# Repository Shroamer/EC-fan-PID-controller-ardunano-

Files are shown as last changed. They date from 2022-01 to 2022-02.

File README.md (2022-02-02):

# EC-fan-PID-controller-ardunano-
**PID controller**
Govern EC fan (0...10v PWM control line) as a PID temperature controller. 
Based on arduino nano v3 (atmega328) dev.board
Termperature sensor is ds18b20 on 1-wire
UI oled screen 128x32 ssd1306 on i2c
UI input encoder with switch on interrupts

## r2.2.5
**beta (in test)**
 + fixed hysteresis function (don't let fan to turn on for some time after it turned off)
 + added destagnation function (turn fan to minPower for some time if no fan activity was found past some time)
 + power icon now can morph to HYST and DEST icons if in these modes.
 + fixed issue with rapid plot overflow while screen is turned off. Now plot array is fulfilled more evenly.
 + fixed value overflow in cycling thru variables

### The device is used to govern EC fan thru 0...10v control line using temperature reading from ds18b20 digital sensor.
- It utilize **ssd1306 128x32 oled display** to show various data and plot graphs.
- Use **encoder with button** to roll thru displays and enter settings. _(with acceleration)_
- ds18b20 **1-wire digital temperature sensor** connected via 3 wire with GND and +5v, _supposedly to make reading routine faster. but i did not find any mentions of id it is faster than on parasitic power_
- Arduino is **powered by** GND and +10v from fan's control line. (my sample use **<35ma** with most pixels white) _I was about to use arduino pro mini, but voltage regulator is too weak to drive arduino and screen, so i turned to nano as it has more powerful +5v voltage regulator_
- PWM signal is raised to 10v and **inverted** with two transistors. _Inversion is used to prevent fan from stopping in case of device failure. Discussible._

### Various variables and data can be set and read:
- Goal temperature.
- PID variables: **kP**, **kI**, **kD** and overall **multiplier** (0.01...100).
- There is a **P+I+D math display** on multiplier screen for you to have deeper understanding of how your config works.
- **MinPower** (some fans can't run at less than 5 or 10%)
- **MaxPower** (sometimes you don't want fan to go full speed)
- You can set **hysteresys delay** in seconds. Think of it as a _cool-down time you need to wait after turning fan off before turning it on again_. It prevents fan from going fast on-off at a margin values.
- There is a **destagnant ventilation** function that can run fan for a while if no fan activity was found recently. _This prevents air from stagnation even there's no need to cool._
- **Temperature offset** can be entered -9.0...9.0^ (0.1^ increment) if your sensor lies linearly.
- **Display timeout** 0...600sec so oled display will last longer.
- You can **turn image 180^** and encoder reading will be inverted.
- Manual and automatic **store setting** to EEPROM on case of power loss.
- You can avoid EEPROM degradation restricting to store current screen. _It is convenient while configuring, but isn't needed after._
- You can play with PId parameters with AUSTOISAVE OFF, and then **restore settings from EEPROM**, or save new settings if new config is better.
- **Temperature graph plot** show last 128 readings for diagnostics.
- **PIDoutput graph plot** show last 128 output values, so you can diagnose and configure PID.
- **Plot sampling rate** can be adjusted averaging up to 250 reading in a single data line in plot, so you can log longer periods. _(sample rate is approx. 3rps)_
- **Automatic vertical range** for graph plots. _Set-mode will change it to full range._
- You can **manually set output rate**. This mode is stored into EEPROM to **return after power loss**. 
- Device maintains manual mode with last stored value **if temp.sensor is lost**.
- Device maintains manual mode **if screen has failed**.

EC-FAN-pid controller r2 2_bb
EC-FAN-pid controller r2 2_schem

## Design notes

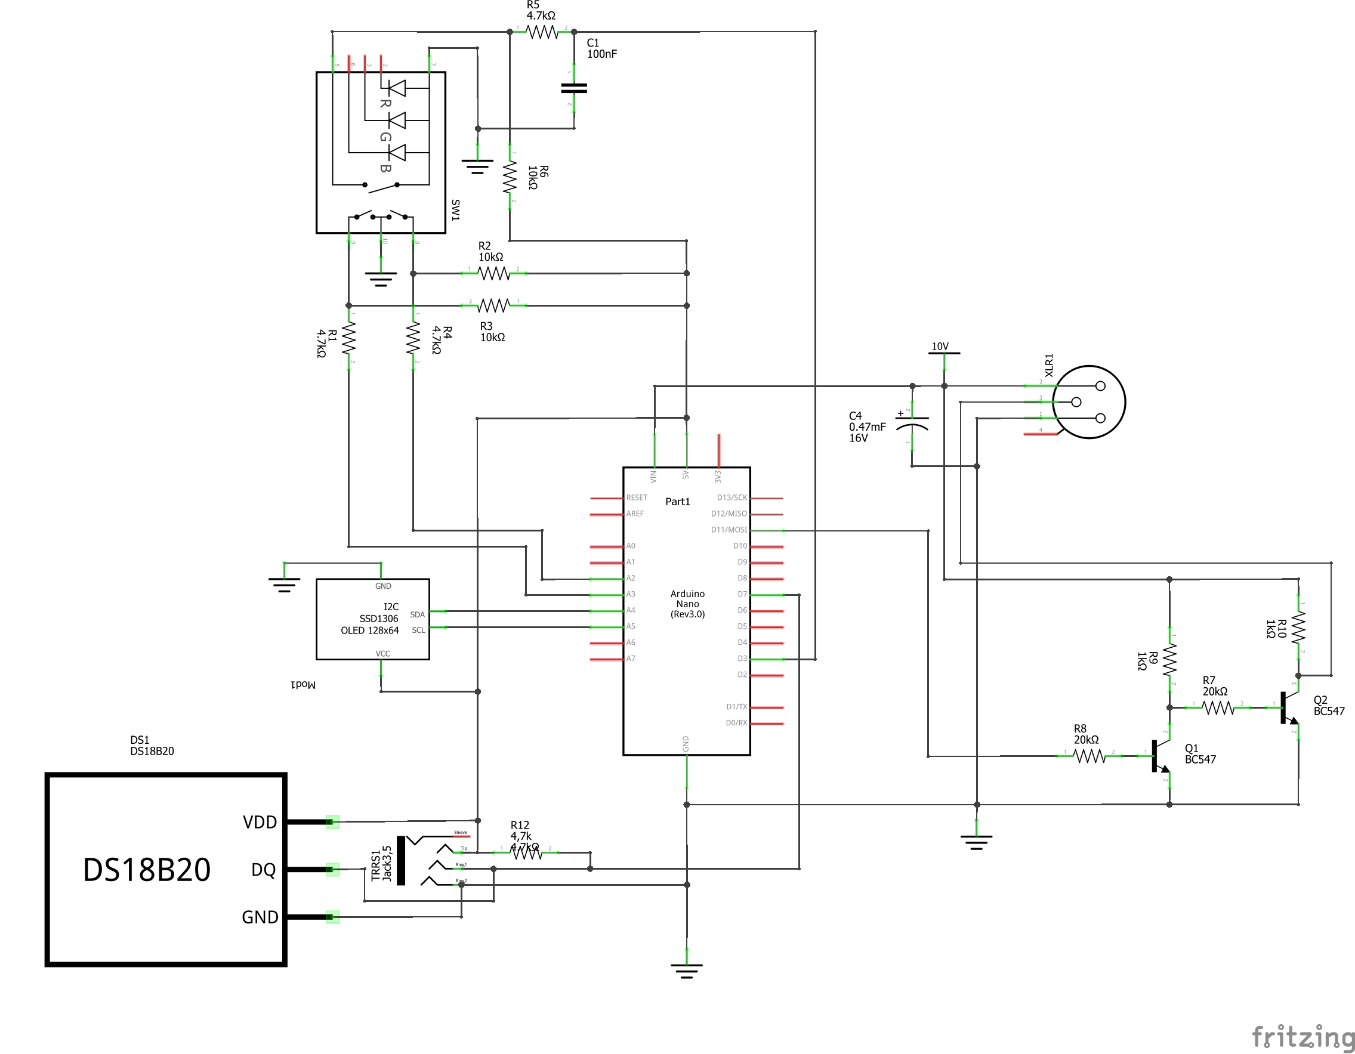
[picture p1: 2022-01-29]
hardware/EC-FAN-pid controller r2.2_schem.png

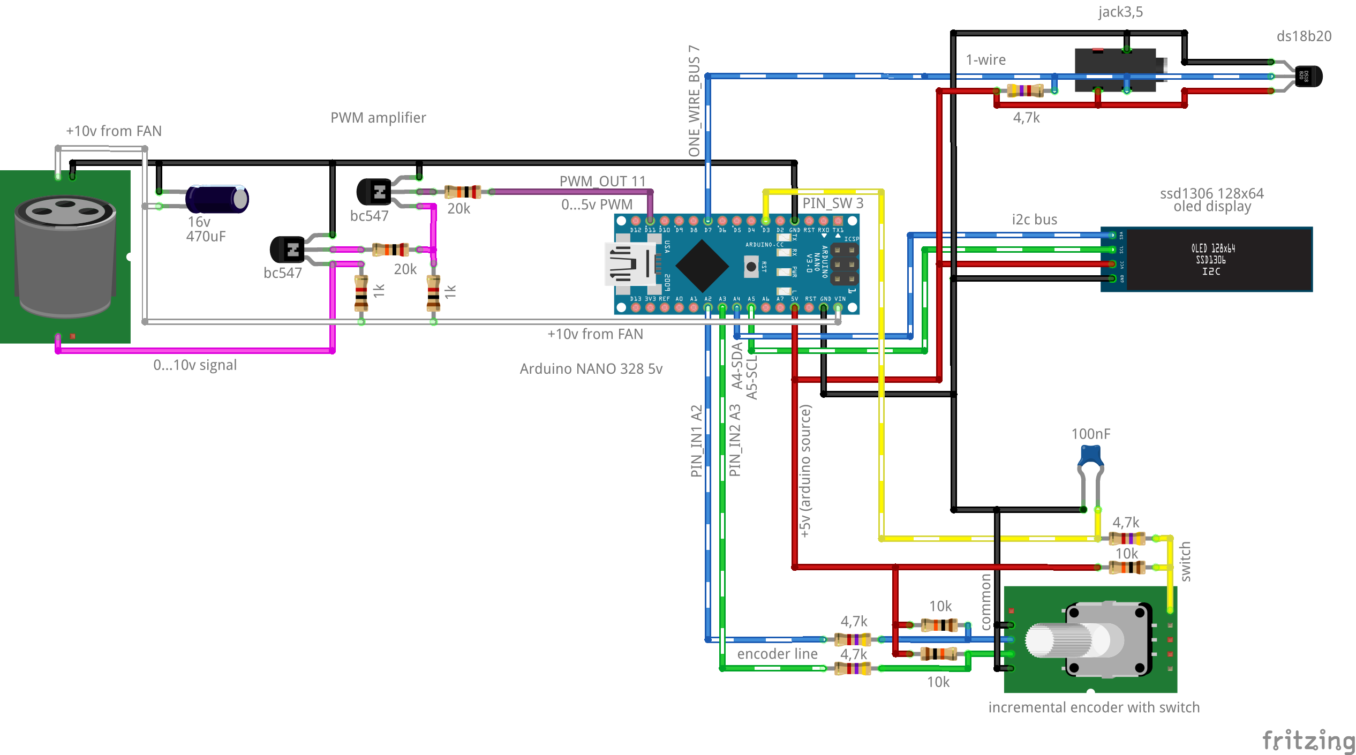
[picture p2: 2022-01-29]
hardware/EC-FAN-pid controller r2.2_bb.png

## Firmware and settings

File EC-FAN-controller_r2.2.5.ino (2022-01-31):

//#define DEBUG_MODE
//#define DEBUG_STATS
//#define DEBUG_LOCATE
//#define BURN_NEW_EEPROM 1 // uncomment for the FIRST time you start with UPDATED EEprom struct (it will save a new defaults)

#define REV_NO "r2.2.5 31.01.22"
/*
  (c) Shroamer, jan`2022 (shroamer(at)gmail(dot)com)
  r2.2.5
    + added destag ventilation time/period screens and variables
    + add destag ventilation time/period routine
    TODO:
      visual properties fix
  29.01.22
  r2.2.4
    + added hysteresis time
    + some code size optimisation
    + some minor changes
  27.12.21
  r2.2.3
    + aproximate >1/x readings
    + fix SENSOR FAIL screen
    + adjust some screens layout
    + adopt icons for:
      read temp   display.write(char(ICONtempRead));
      goal temp   display.write(char(ICONtempGoal));
      power       display.write(char(ICONoutput));
      error       display.write(char(ICONerror));
      PIDerror    display.write(char(PIDerror));
    + adopt icons for plot screens:
      min range   display.write(char(ICONminRange));
      max range   display.write(char(ICONmaxRange));
    + fixed: if waked by sensFail, it will remember 0 as lastScreen and will never wake again (wake to 0)
    + fixed: when sensFail occured while manual mode, after recovery it will not return to manual, so isConstPower flag is introduced
    + fixed: plotting continues even in isConstMode.

  26.12.21
  r2.2.2
    + increase ds18b20 ADC reading resolution from 9 to 11 bits
        increased PID output smoothness
    + skipping ds18b20 readings delay
        UI becomes extremely fast (FPS x10)
        plot sampling becomes more even
    + change Tadj increment from 0.5 to 0.1 degree because of precise readings
        more precise Tadjusment is possible
    + fix a bug when wake up by encoder did not perform recall of last screenMode
        waking uo with encoder with no problems
    + fixed tAdj bar when negative
    + change PIDx multiplier bar style
    + move PIDx screen after P, I, D
    + fix prefilled by nulls plot data. now it is filled with actual temperature


  Local Search links (copy it and search to find corresponding place):
  // ***** PUT NEW SCREEN HERE *****
  // ***** INSERT NEW SCREEN INTO SCREEN SEQUENCE HERE *****
  // ***** DEFINE WHAT TO APPLY AFTER EXITING SETMODE HERE *****
  // ***** PUT YOUR NEW EEprom DATA HERE *****

  ENCODER LIB LINK: https://github.com/mathertel/RotaryEncoder/blob/master/src/RotaryEncoder.cpp
  PID code sample took here :http://electronoobs.com/eng_arduino_tut24_code3.php

  hardware:
  thermal sensor dallas ds

  arduino wiring:
  VIN ---> +10v input from FAN source
  GND ---> GND input from FAN source
  D3  ---> encoder switch (to GND)
  D7  ---> 1-wire bus for DS18b20
  D11 ---> PWM output (thru amplifyer to 0...10v FAN input)
  A2  ---> encoder left (to GND)
  A3  ---> encoder right (to GND)
  A4  ---> ssd1306 display SDA
  A5  ---> ssd1306 display SCL
*/
#define PWM_OUT 11 // pin for PWM output (3,5,6,9,10,11)
#define ONE_WIRE_BUS 7 // data pin for dallas ds18b20 sensor
#define PIN_IN1 A2 // rotary encoder pin1
#define PIN_IN2 A3 // rotary encoder pin2
#define PIN_SW 3 // rotary encoder button
#define OLED_RESET     -1 // Reset pin # (or -1 if sharing Arduino reset pin)

#include <Arduino.h>
//#include <RotaryEncoder.h> // https://github.com/mathertel/RotaryEncoder/blob/master/src/RotaryEncoder.cpp
#include <Rotary.h> // http://www.buxtronix.net/2011/10/rotary-encoders-done-properly.html?m=1
#include <EEPROM.h> // EEprom for storing settings
#include <OneWire.h> // for dallas ds18b20 sensor reading
#include <DallasTemperature.h> // for dallas ds18b20 sensor reading
#if defined(DEBUG_MODE)
#include <SPI.h> // include to enable serial debugging
#endif
#include <Wire.h> // i2c for ssd1306
#include <Adafruit_GFX.h> // for ssd1306 display
#include <Adafruit_SSD1306.h> // for ssd1306 display
#define SCREEN_WIDTH 128 // OLED display width, in pixels
#define SCREEN_HEIGHT 32 // OLED display height, in pixels

// Declaration for an SSD1306 display connected to I2C (SDA, SCL pins)
Adafruit_SSD1306 display(SCREEN_WIDTH, SCREEN_HEIGHT, &Wire, OLED_RESET);

OneWire  oneWire(ONE_WIRE_BUS);  // init OneWire on pin 10 (a 4.7K resistor connecting +5 with DATA is necessary)
DallasTemperature sensors(&oneWire); // Pass our oneWire reference to Dallas Temperature ds18b20 sensor.

// A pointer to the dynamic created rotary encoder instance. This will be done in setup()
//RotaryEncoder *encoder = nullptr;

//   UI VARIABLES
byte screenMode = 1; // screen mode: 0=off; 1=main screen;
byte screenLast = 1; // store last screen mode to wake into
byte storeScreen = 0; // should we store screen when go sleep? (wears EEPROM if menu used actively)
byte setMode = 0; // 0: scroll to list screenMode, click to enter setMode; 1: scroll to change value, click to apply;
//   UI TIME:
unsigned int screenTimeout = 150; //store screen timeout in seconds
volatile unsigned long lastActionTime; // store millis() at lst call action. dim after timeout (float?)
//   UI FLAGS:
bool displayMissing = 0; // flag set if no display found
bool displaySleep = 0; // flag display sleeping
volatile byte displayRotate = 0; // rotate display flag
bool isConstPower = 0; // flag to act in const power mode (for manual, nosensor, or nodisplay mode
bool isAutoSave = 0; // should we automatically save settings?
bool returnToManual = 0; // flag if we should return to manual mode after sensFail fixed

//   UI PLOT SCREEN VARIABLES:
int screenTempArray[128];
byte screenPidArray[128];
unsigned int keepSample = 1; // take 1 sample of keepSample. If set to 4 it will skip 3 and keep 1 next.
unsigned int keepSampleIndex = 0; // index of sample to keep
unsigned long tempApproxSum = 0;
unsigned long powerApproxSum = 0;
byte arrayIndex = 0; // where we're in array
//int rangeMin = 0; // keep min/max values of array so we can set up vertical scale
//int rangeMax = 0;

// ***** INSERT NEW SCREEN INTO SCREEN SEQUENCE HERE *****
#define UIMAIN_SCREEN 1
#define UIP_SCREEN 2
#define UII_SCREEN 3
#define UID_SCREEN 4
#define UIPID_SCREEN 5
#define UIPOWERMIN_SCREEN 6
#define UIPOWERMAX_SCREEN 7
#define UIHYSTERESISTIME_SCREEN 8
#define UIDESTAGPERIOD_SCREEN 9
#define UIDESTAGTIME_SCREEN 10
#define UITADJ_SCREEN 11
#define UITIMEOUT_SCREEN 12
#define UISCREENROTATE_SCREEN 13
#define UISTORESCREEN_SCREEN 14
#define UISETSAVE_SCREEN 15 // value of save-settings screenmode, so we don't store this screen into memory
#define UISETLOAD_SCREEN 16
#define UIPLOTTEMP_SCREEN 17
#define UIPLOTPID_SCREEN 18
#define UICONST_SCREEN 19 // value of const-mode screenmode; set the last available ScreenMode to cycle

#define ICONtempRead    0xb
#define ICONtempGoal    0xc
//#define ICONoutput      0xe3
char ICONoutput = 0xe3;
#define ICONminRange    0x18
#define ICONmaxRange    0x19
#define ICONerror       0x01
#define ICONPIDerror    0xf0
#define ICONselect      0x10

// Rotary encoder is wired with the common to ground and the two
// outputs to pins 2 and 3.
Rotary rotary = Rotary(PIN_IN1, PIN_IN2);

//   ENCODER VARIABLES:
#define ENC_MULT 50 // encoder acceleration divider (more - slower)

//   INPUT HANDLERS:
int encIncrement = 0; // used outside of interrupt routine
volatile int encoderIncrement = 0; // stores negative each step CCW, positive each step CW, 0 if no or null sum action is registered

//   INPUT FLAGS:
volatile bool switchAction = 0; // 1 if an interrup action registered
//bool encoderCheck = 0; // call to check news from encoder
bool encoderAction = 0; //some specific action found from encoder(increment!=0)



//   TEMPERATURE CONTROL VARIABLES:
int tempIntC = 0; // integer of current temperature value in decadegree (1/10 degree) celsius
int tempGoal = 190; // goal temperature in decadegrees (180 = 18.0 degree)
int tempAdj = 0; // shifting sensor data by this value (1/10 deg)
int PID_err = 0; //= tempGoal - tempIntC; // to calculate temperature
int PID_err_prev = 0;
int PID_value = 0; // in-math PID value
int PID_output = 0; // output is truncated by min/max Power
//int PID_output_prev = 0;
int outVal = 0;

//int8_t PID_change = 0; // store -1 - if PID has falled to 0; 0 - if it is stable; 1 - if it was rised

//   PID constants
int kp = 50; //90
int ki = 8; //30
int kd = 23; //80
int kpid = 100; //afterall coefitient(actually, it will be divided by /100)
//   PID values
int PID_p = 0;
int PID_i = 0;
int PID_d = 0;
//   PID time management:
float elapsedTime, Time, timePrev;

//   OUTPUT POWER MANAGEMENT
byte minPower = 35;
byte maxPower = 255;
byte constPower = 96;

unsigned int HYSTtime = 0; // store hysteresis time value in seconds
unsigned long HYSTcycleStart = 0; // essentially is fanTurnedOffTimer for hysteresis timer, so it can be not set when falling by DESTtimer end.
//unsigned long fanTurnedOffTimer = 0; // store timer value of last fan turn_off
//unsigned long fanTurnedOnTimer = 0; // timer to keep moment fan was turned on last time
byte lastFANvalue = 0; //last PID value to compare is anything changed
byte actualFANvalue = 0;
//bool hysteresisHold = 0; // if==1 then keep output to 0
bool HYSTwithin = 0; // returns 1 if now is hysteresis hold time

unsigned long DESTcycleStart = 0; // essentially is fanTurnedOffTimer for destag timer, so it can be truncated in case of overflow.
unsigned int DESTtime = 0; // DeStagnant fentilation time in seconds. Fan will be turned on for this time
unsigned int DESTperiod = 0; // destagnant fentilation period in minutes. Fan will be turned on if FAN is off this long

bool DESTaction = 0; // flag destag is need action
bool DESToverflow = 0; // flag to not to reset hysteresis timer
#define HYST_TIME_MULT 1000L
#define DEST_PERIOD_MULT 60000L // multiplier of DESTperiod in ms (1min)
#define DEST_TIME_MULT 1000L // multiplier of DESTtime in ms (1sec)

//   SENSOR FLAGS:
bool sensFail = 0; // temperature sensor failed flag
bool sensNewData = 0; // we have new readings
#define SENSOR_RESOLUTION 11  //set internal ds18b20 ADC resolution 9...12  
unsigned long sensLastRead = 0;
int sensReadDelay = 750 / (1 << (12 - SENSOR_RESOLUTION));

//   EEPROM data storage:
// ***** ADD YOUR NEW EEprom VALUE ADDRESS HERE ***** (TODO)
#define ADDR_tempGoal         0 // +2 int
#define ADDR_kp               2 // +2 int
#define ADDR_ki               4 // +2 int
#define ADDR_kd               6 // +2 int
#define ADDR_kpid             8 // +2 int
#define ADDR_minPower         10 // +1 byte
#define ADDR_maxPower         11 // +1 byte
#define ADDR_isConstPower     12 // +1 byte
#define ADDR_constPower       13 // +1 byte
#define ADDR_tempAdj          14 // +2 int
#define ADDR_timeOut          16 // +2 u_int
#define ADDR_storeScreen      18 // +1 byte
#define ADDR_displayRotate    19 // +1 byte
#define ADDR_isAutoSave       20 // +1 byte
#define ADDR_keepSample       21 // +2 u_int
#define ADDR_HYSTtime  23 // +2 u_int
#define ADDR_DESTtime       25 // +2 u_int
#define ADDR_DESTperiod     27 // +2 u_int
#define ADDR_screenMode       1023 // byte, store it in the last bit 1023 = 0x3FF

// coordinates for PID screen elements: //PROGMEM
const byte coordsP[3][3][2] = {   // 3 screens(P,I,D), 3 elements(title,value,math), 2 coordinates(x,y)
  {{58, 0}, {50, 3}, {98, 3}},    // for P screen
  {{68, 0}, {50, 0}, {98, 0}},    // for I screen
  {{68, 0}, {50, 0}, {98, 0}}     // for D screen
};
const byte coordsI[3][3][2] = {
  {{68, 16}, {50, 16}, {98, 16}}, // for P screen
  {{58, 8},  {50, 12}, {98, 12}}, // for I screen
  {{68, 8},  {50, 8},  {98, 8}}   // for D screen
};
const byte coordsD[3][3][2] = {
  {{68, 24}, {50, 24}, {98, 24}}, // for P screen
  {{68, 24}, {50, 24}, {98, 24}}, // for I screen
  {{58, 16}, {50, 20}, {98, 20}}  // for D screen
};
const byte coordsPIDarrow[3][2] = { // PID arrow coordinates: 3 screens(P,I,D), 2 coordinates(x,y)
  {44, 3}, // for P screen
  {44, 12}, // for I screen
  {44, 20}  // for D screen
};

// coordinates for min\max Power screen elements:
const byte coordsMin[2][2] = { // 2 screens (min, max), 2 coordinates (x,y)
  {1, 17},
  {5, 21}
};
const byte coordsMax[2][2] = { // 2 screens (min, max), 2 coordinates (x,y)
  {95, 21},
  {90, 17}
};

// coordinates destag time/period screen elements:
/*
  const byte coordsDESTtime[2][2] = { // 2 screens (time, period), 2 coordinates (x,y)
  {1, 17},
  {5, 21}
  };
  const byte coordsDESTperiod[2][2] = { // 2 screens (time, period), 2 coordinates (x,y)
  {95, 21},
  {90, 17}
  };
*/

void setup() {
#if defined(DEBUG_MODE)
  Serial.begin(115200);
#endif
  pinMode(PWM_OUT, OUTPUT); // init pin for PWM - fast as possible, so the fan can't go wild (inverted output circuitry)
  analogWrite(PWM_OUT, 255); // set default power (inverted output, so 255 is 0%)

  pinMode(PIN_SW, INPUT_PULLUP); // init pin for switch interrupt
  attachInterrupt(digitalPinToInterrupt(PIN_SW), switchInt, FALLING); // [CHANGE, RISING FALLING]switch interrupt

  // SSD1306_SWITCHCAPVCC = generate display voltage from 3.3V internally
  if (!display.begin(SSD1306_SWITCHCAPVCC, 0x3C)) { // Address 0x3C for 128x32
    displayMissing = 1;
  }

  sensors.begin(); // Start up ds18b20 library
  sensLastRead = millis(); // resetting timer, because now delay is still included within requestTemperatures, so we need to pass
  sensors.setResolution(SENSOR_RESOLUTION); //before each measurement, set internal ADC resolution 9...12
  sensors.requestTemperatures();  // Send the command to get temperatures
  delay(sensReadDelay);
  tempIntC = readTemp() * 10; //read the ds18b20 sensor and store it in integer in decadegree format to fulfill array
  screenTempArrayInit();   // init screenTempArray
  screenPidArrayInit();
  sensors.setWaitForConversion(false); // exclude delay within requestTemperatures for smooth UI in loop

#if defined(BURN_NEW_EEPROM)
  settingsPut(); // save new EEProm for the first time
#endif
  settingsGet(); // load seeting from eeprom
  if (displayRotate) { // update display rotation
    display.setRotation(2);
  }
  screenLast = EEscreenModeGet();
  screenMode = screenLast;
  if (!displayMissing) { // setup display
    splashScreen();
  }

  //  To use other pins with Arduino UNO you can also use the ISR directly.
  // Here is some code for A2 and A3 using ATMega168 ff. specific registers.
  // Setup flags to activate the ISR PCINT1.
  // You may have to modify the next 2 lines if using other pins than A2 and A3
  PCICR |= (1 << PCIE1);    // This enables Pin Change Interrupt 1 that covers the Analog input pins or Port C.
  PCMSK1 |= (1 << PCINT10) | (1 << PCINT11);  // This enables the interrupt for pin 2 and 3 of Port C.
  /*setFanDim(0);
    setFanDim(1);
    setFanDim(0);*/
  lastActionTime = millis(); // reset screen timeout
}

void loop() {
  //if (encoderCheck) encoderRoutine(); // encCHECK: call to process new encoder data on flag rise before drawing UI
  if (!displayMissing) {  //   DISPLAY is OK
    if (!isConstPower) {  //   PIDmode ACTION: calc PID, apply result (TODO - apply min/max to result)
      PID_DEST_HYST();
    }
    else {                //   CONSTmode ACTION: apply constPower to output, set screenMode UICONST_SCREEN if not 0 (constpower settings)
      if (screenMode) screenMode = UICONST_SCREEN;
      if (!setMode) setMode = 1;
      //tempIntC = readTemp() * 10;
      calculatePID();
      takePlotSample();     //   UI PLOT SCREEN SAMPLING
      setFanDim(255 - constPower); // set the const power value
    }
    if ((millis() - lastActionTime) > (screenTimeout * DEST_TIME_MULT) && screenMode != 0) { // SLEEP TIMEOUT: goto SLEEP, store last screenmode
      if (!sensFail) screenLast = screenMode; // store screenMode for wake (only in normal mode)
      if (storeScreen) EEscreenModePut(); //save screen to eeprom only when it different (save eeprom life)
      screenMode = 0;
    }
    if (switchAction && !screenMode) { // WAKEUP by SWITCH: - wake up and setup actual screen
      if (!isConstPower) { // DISPLAY, SWITCH & SLEEP @PID: waking, going to start screen
        screenMode = screenLast;
      }
      else { // DISPLAY, SWITCH & SLEEP @CONST: switch at ConstPower rules to 9 screenMode with enabled scrolling
        screenMode = UICONST_SCREEN;
        setMode = 1;
      }
      switchAction = 0;
    }

    drawUi(); // MAIN UI CALL
  }
  else { // if the DISPLAY IS MISSING we have to get in alternative constant power mode with adjustment and automatic settings saving
    digitalWrite(13, 1);
    if (switchAction) {
      switchAction = 0;
      EEPROM.put(ADDR_constPower, constPower);
    }
    if (encoderAction) { // call to process new encoder data on flag rise
      encIncrement = nullEncoder(); // retrieve increment data and reset encoder state/flag
      constPower = scrollInt(constPower, encIncrement, 0, 255, 0); // increment constPower
      setFanDim(constPower); // set the const power value
    }
  }

#if defined(DEBUG_STATS)
  //static unsigned long lastDataSend = millis();
  //if (millis() - lastDataSend > 500) {
  //  lastDataSend = millis();
  //Serial.print(F(" SCR-"));  Serial.print(int(screenMode));
  //Serial.print(F(" SET-"));  Serial.print(int(setMode));
  //Serial.print(F(" TMP-"));  Serial.print(int(tempIntC));
  //Serial.print(F(" GOA-"));  Serial.print(int(tempGoal));
  //Serial.print(F(" PID-"));  Serial.print(int(PID_value));
  //Serial.print(F(" CON-"));  Serial.print(int(isConstPower));
  //Serial.print(F(" SF-"));  Serial.print(int(sensFail));
  //Serial.print(F(" DR-"));  Serial.print(int(displayRotate));
  //Serial.print(F(" STO-")); Serial.print(screenTimeout * 1000L);
  //Serial.print(F(" AIN-")); Serial.print(arrayIndex);
  //Serial.print(F(" ROT-")); Serial.print(displayRotate);
  //Serial.print(F(" kpid-"));  Serial.print(int(kpid));
  //Serial.print(F(" TOL-")); Serial.print((screenTimeout * DEST_TIME_MULT) - (millis() - lastActionTime));
  unsigned long timeNow = millis();
  if (DESTaction)Serial.print(F(" DES:"));  else Serial.print(F(" des:"));
  Serial.print((timeNow - DESTcycleStart) / 1000);
  Serial.print(F("/"));  Serial.print(long(timeNow - (DESTcycleStart + (DESTperiod * DEST_PERIOD_MULT)) ) / 1000);
  Serial.print(F("/"));  Serial.print(long(timeNow - (DESTcycleStart + (DESTperiod * DEST_PERIOD_MULT) + (DESTtime * DEST_TIME_MULT)) ) / 1000);

  //Serial.print(F(" TON:"));  Serial.print((timeNow - fanTurnedOnTimer) / 1000);
  //Serial.print(F("/"));  Serial.print(long(timeNow - (fanTurnedOnTimer + (DESTtime * DEST_TIME_MULT))) / 1000);

  if (HYSTwithin) Serial.print(F(" HYS:"));  else Serial.print(F(" hys:"));
  Serial.print(long(timeNow - (HYSTcycleStart + (HYSTtime * HYST_TIME_MULT))) / 1000);
  //Serial.print(F(" FV:"));  Serial.print(lastFANvalue);
  //Serial.print(F("/"));  Serial.print(actualFANvalue);
  Serial.print(F(" PID:"));  Serial.print(int(PID_output));
  Serial.print(F(" OUT:"));  Serial.print(int(outVal));
  //Serial.print(F("   "));  Serial.print(timeNow - lastActionTime);
  Serial.println();
  //}
#endif
}

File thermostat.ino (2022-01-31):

byte calculatePID() { // PID calculation routine
  tempIntC = readTemp() * 10.0; //read the ds18b20 sensor and store it in integer in decadegree format
  if (sensNewData) {
    //PID_output_prev = PID_output;
    PID_err = tempGoal - tempIntC; // +5 calculate error between set value and real temperature
    PID_p = float(0.01 * kp * PID_err); //Calculate the P value
    PID_i = float(0.01 * PID_i + (ki * (PID_err))); //Calculate the I value in a range on +-5
    //For derivative we need real time to calculate speed change rate
    timePrev = Time; // the previous time is stored before the actual time read
    Time = millis(); // actual time read
    elapsedTime = (Time - timePrev) / 1000;
    //Now we can calculate the D value
    PID_d = float(0.01 * kd * ((PID_err - PID_err_prev) / elapsedTime));
    //Final total PID value is the sum of P + I + D
    PID_value = (float(float(kpid) / 100.00) * float(PID_p + PID_i + PID_d)) * -1L; // kpid/100 - apply afterall coefitient
    // map PID value: shift bottom to minPower, truncate top to maxPower to fit within range minPower...maxPower
    //PID_value = map(PID_value, 0, 255, minPower, maxPower);
    //We define PWM range between 0 and 255
    //PID_value = truncInt(PID_value, 0, 255);
    // truncInt(PID_value, minPower, maxPower);
    PID_output = PID_value;
    if (PID_output > maxPower) {
      PID_output = maxPower;
    }
    if (PID_output < minPower) {
      PID_output = 0;
    }
    //Now we can write the PWM signal to the FAN
    //setFanDim(PID_value);
    PID_err_prev = PID_err;     //Remember to store the previous error for next loop.
    return (PID_output);
  }
}

void PID_DEST_HYST() {
  calculatePID();//make all necessary math involved in PID
  getHYST(); // >HYSTwithin(0,1)
  getDEST(); // >DESTaction(0,1)
  outVal = PID_output;
  ICONoutput = 0xe3;
  if (HYSTwithin) {
    outVal = 0;
    ICONoutput = 0x19;
  }
  if (DESTaction && !PID_output) {
    outVal = minPower;
    ICONoutput = 0x18;
  }
  //takePlotSample();     //   UI PLOT SCREEN SAMPLING
  // now we'll aaply output value and take plot sample
  if(sensNewData){
    sensNewData=0;
    takePlotSample();     //   UI PLOT SCREEN SAMPLING
  }
  setFanDim(255 - outVal); //Now we can write the PWM signal to the FAN
}

void getHYST() {
  if (HYSTtime) {
    unsigned long timeNow = millis();
    if (timeNow > HYSTcycleStart && timeNow < HYSTcycleStart + (HYSTtime * HYST_TIME_MULT))  HYSTwithin = 1;
    else HYSTwithin = 0;
  }
  else HYSTwithin = 0;
}

void getDEST() {
  if (DESTperiod && DESTtime) {
    unsigned long timeNow = millis();
    unsigned long DESTcycleEnd = DESTcycleStart + (DESTperiod * DEST_PERIOD_MULT) + (DESTtime * DEST_TIME_MULT);
    if (DESTcycleStart < timeNow) { // check if fan was turned off in the past
      if (timeNow < (DESTcycleStart + (DESTperiod * DEST_PERIOD_MULT))) DESTaction = 0;
      else {
        if (timeNow > DESTcycleEnd) { // overflow,
#if defined(DEBUG_MODE)
          Serial.println(F("DEST!"));
#endif
          DESTcycleStart = millis();
          DESToverflow = 1;
          DESTaction = 0;
        }
        else DESTaction = 1; // within TIME range
      }
    }
  }
  else DESTaction = 0;
}

float readTemp() { // used to get current temperature from a single ds18b20 sensor
  unsigned long timeSinceLastRead = millis() - sensLastRead;
  static float tempC;
  //Serial.print(timeSinceLastRead);
  //Serial.print(" ");
  if (timeSinceLastRead >= sensReadDelay) {
    tempC = sensors.getTempCByIndex(0); // We use the function ByIndex, and as an example get the temperature from the first sensor only.
    if (tempC != DEVICE_DISCONNECTED_C) {  // Check if reading was successful
      //Serial.println(tempC);
      if (sensFail == 1) { // SENSOR JUST RECOVERED FROM FAIL: recover last screen mode if sensoor ok, clear flag
        digitalWrite(13, 0);
        wakeScreen();
        if (!returnToManual) {
          screenMode = screenLast;
          setMode = 0;
          isConstPower = 0;
        }
        else {
          screenMode = UICONST_SCREEN;
          setMode = 1;
          isConstPower = 1;
        }
        sensFail = 0;
        lastActionTime = millis();
        if (screenMode != UICONST_SCREEN) { // back from constPower if was not in UICONST_SCREEN
        }
      }
      if (tempAdj) tempC += float(tempAdj) / 10.0; // implement temperature adjust shift
      sensNewData = 1;
      sensors.setResolution(SENSOR_RESOLUTION); //before each measurement, set internal ADC resolution 9...12
      sensors.requestTemperatures();  // Send the command to get temperatures
      sensLastRead = millis();
      return (tempC);
    }
    else { // TEMPERATURE SENSOR FAILED!!! (save to constant mode)
      if (!sensFail) { // SENSOR JUST FALLED INTO FAIL MODE
        digitalWrite(13, 1);
        wakeScreen();
        MSGsensorFail();
        delay(1500);
        if (isConstPower)returnToManual = 1;
        else returnToManual = 0;
        if (screenMode) screenLast = screenMode; // remember last screen
        sensFail = 1;
        lastActionTime = millis();
      }
      isConstPower = 1;
      screenMode = UICONST_SCREEN; // go to manual mode
      setMode = 1;
      sensLastRead = millis();
      return (65535);
    }
  }
  else { //it is not time to get new readings
    sensNewData = 0;
    //Serial.print("wait ");
    //Serial.println(sensReadDelay);
    return (tempC);
  }
}

void setFanDim(int dimVal) { // call to set correct PWM at pin, so FAN works correct
  lastFANvalue = actualFANvalue;
  actualFANvalue = 255 - dimVal;
  analogWrite(PWM_OUT, dimVal);
  //store time of last turning off if PID just went down
  if (!actualFANvalue && lastFANvalue) FANwentOff();
  //store time of last turning on if PID just went up
  if (actualFANvalue && !lastFANvalue) FANwentOn();

}

void FANwentOff() {
  unsigned long timeNow = millis();
  //  fanTurnedOffTimer = timeNow;
  DESTcycleStart = timeNow;
  if (!DESToverflow) HYSTcycleStart = timeNow; // don't reset hyst timer if overflowed DEST
  else DESToverflow = 0;
#if defined(DEBUG_MODE)
  Serial.println(F("TURNED OFF"));
#endif
}

void FANwentOn() {
  //  fanTurnedOnTimer = millis();
#if defined(DEBUG_MODE)
  Serial.println(F("TURNED ON"));
#endif
}

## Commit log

2022-01-24 create r2.2.4
    TODO:
    - add hysteresis timer to define how long to keep fan off before it can be turned on
    - add unstall mode and configs, so if fan is continuously off for some time it can be turned on for a little to remove stall air.
    [drawUI.ino, eeprom.ino, input_int.ino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]
2022-01-29 update main fork to last release, add hardware files
    [EC-FAN-pid controller r2.2.fzz]
2022-01-31 Major r2.2.5 fixes
    + added DESTAG function
    + fixed power manifold to let HYST and DEST work properly
    + fixed power data source for plot and sampling range
    + fixed plot overflow with screen sleeping. Now data is collected much more evenly.
    + fixed variable cycling function
    + minor fixes.
    [EC-FAN-controller_r2.2.5.ino, drawUI.ino, eeprom.ino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]
